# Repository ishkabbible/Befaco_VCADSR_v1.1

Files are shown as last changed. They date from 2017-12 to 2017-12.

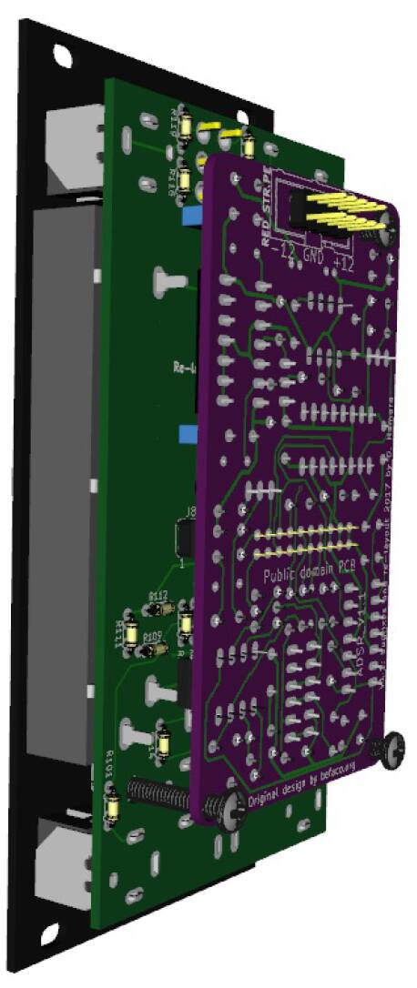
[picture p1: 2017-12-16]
full assembly 3D back final 2.jpg

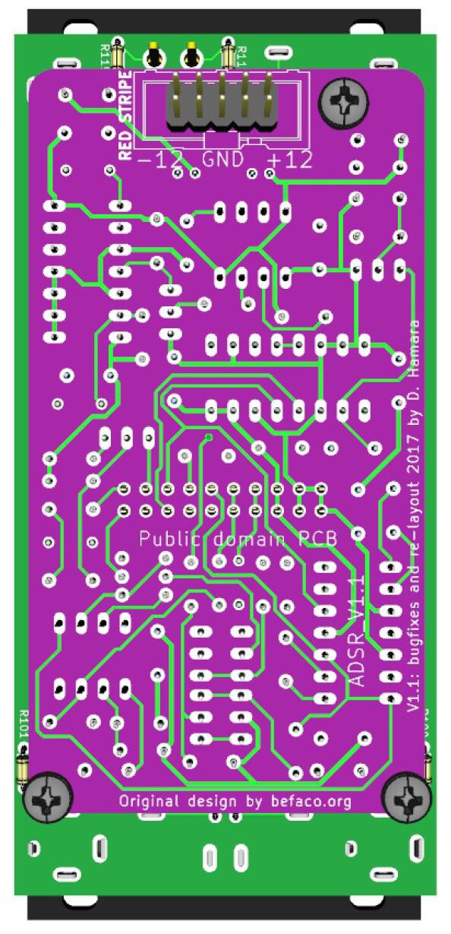
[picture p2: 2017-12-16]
full assembly 3D back final 1.jpg

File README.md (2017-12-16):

# Befaco_VCADSR_v1.1
Hamara Labs modified version of the Befaco version 1 VCADSR

The original files from Befaco are available here:
https://www.befaco.org/en/sinte-modular/en-produccion/vc-adsrv1/

Original design by Juergen Haible (http://www.jhaible.info/tonline_stuff/hj_vc_hadsr.html)

and Tom Gamble (http://synthdiy.fonitronik.de/files/4613/8287/9784/vcradsr.pdf)

I fixed a couple of bugs
  1) the inputs to the unused half of the 4013 were left floating - they are now properly grounded
  2) The trigger input to the used half of the 4013 was effectively floating whenever there was no gate input present, 
  due to the reverse biased D2. Added R26 to hold the trigger input at ground when D2 is reverse biased
  3) A retrigger bug was identified by someone somewhere, and photos of a haywire patch have been routinely distributed on line.
  That mod has been incorporated on the PCB as D6 and T8
  
I also updated the layout to use parts that are more readily available than the parts used in the original design. 
  
This repository contains 2 PCBs (FRONT and BACK) and one panel, all in KiCAD (http://kicad-pcb.org/)

The BOM is at https://docs.google.com/spreadsheets/d/1yNOWsHSHRAM60BiDUVynL0L72_J8PpAY8x3tWKFwJsM/edit?usp=sharing
This file takes precedence over the BOM in the assembly instructions document.

PCBs and panels *may* be available from Hamara Labs. Email HamaraLabs1 (at) gmail (dot) com to find out.

I believe all these files are correct, but I make no warranty whatsoever. Build at your own risk. If you find any problems with these files, please contact Hamara Labs at HamaraLabs1 (at) gmail (dot) com and I will update the files.

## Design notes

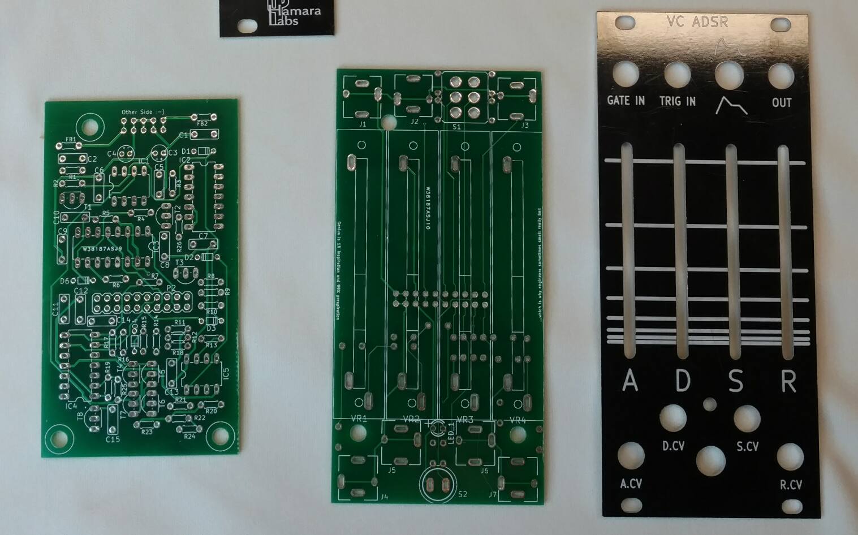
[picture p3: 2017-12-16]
VCADSR PCBs and panel.jpg

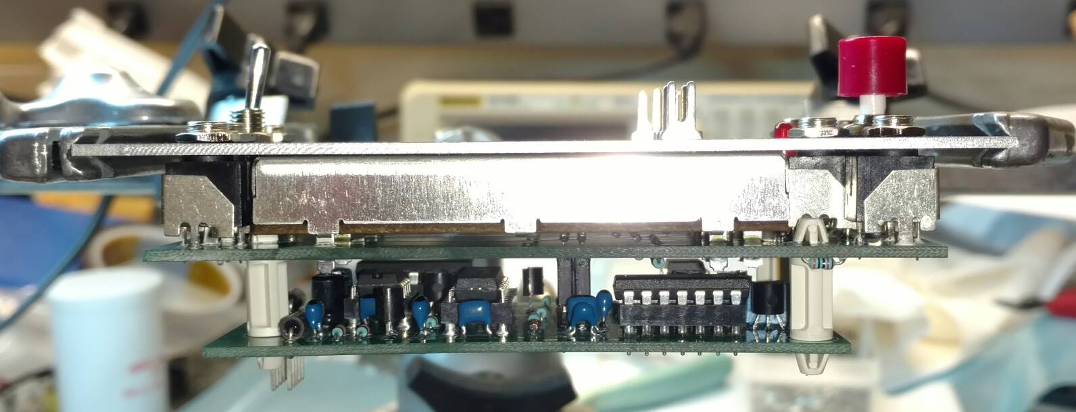
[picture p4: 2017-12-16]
VCADSR built 3 side view.jpg

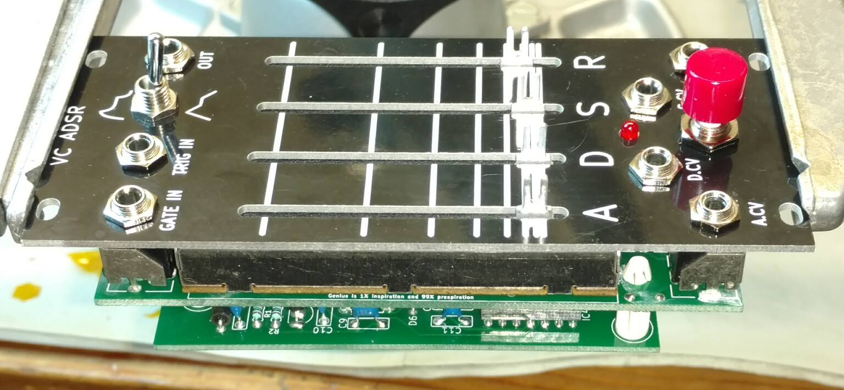
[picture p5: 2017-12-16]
VCADSR built 4 side perspective view.jpg

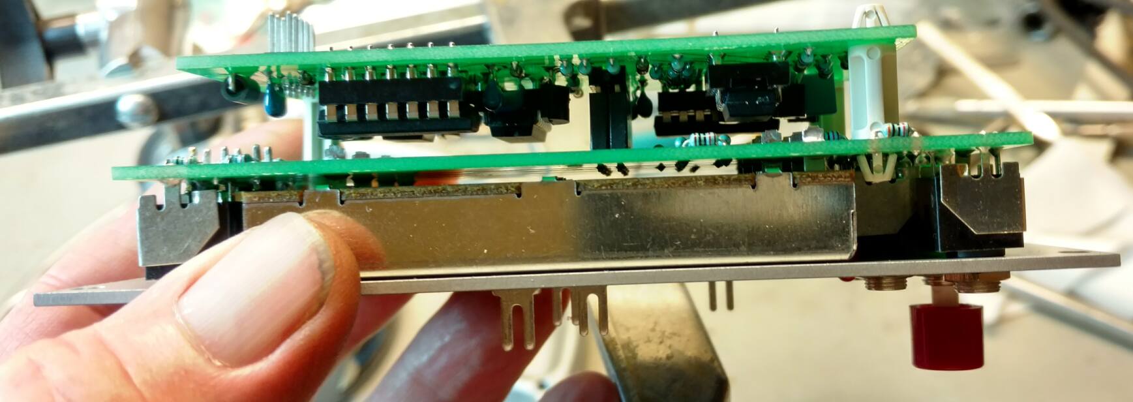
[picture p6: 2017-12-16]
VCADSR built 2 under sliders.jpg

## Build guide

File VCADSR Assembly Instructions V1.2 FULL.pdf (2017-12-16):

A

# Befa ssem

# co VC bly

2017

# CADS y Inst

# Dave Hamar

# SR V ructi

ra

1.1

# ons

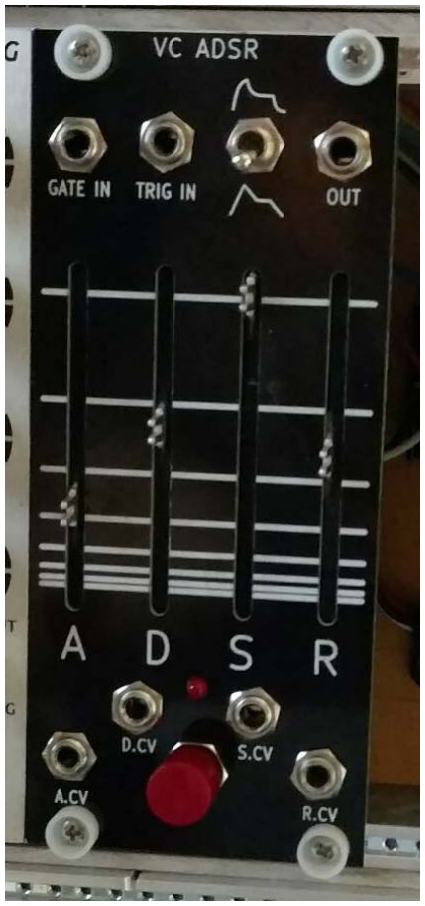
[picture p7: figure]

# Assembly Instructions

The back PCB assembly is very straightforward (Figure 1). Just remember that you only have 12mm of clearance between the 2 boards, so you don't want anything sticking up any farther than necessary. There IS room for low‐profile machined sockets (listed as OPTIONAL in the BOM) if you like socketing your chips.

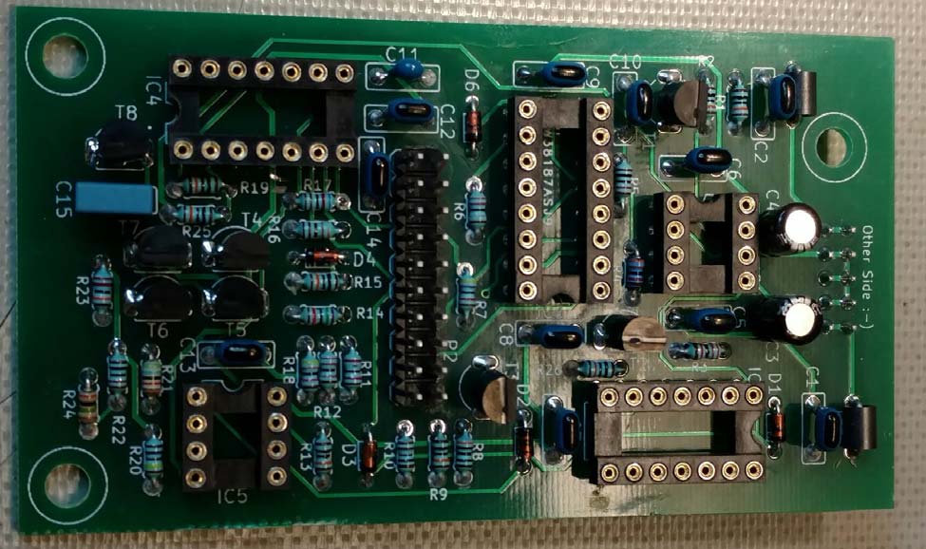
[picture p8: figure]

# Figure 1: Assembled BACK PCB. Mount T1 ‐ T8 close to the board

Assembly of the front PCB to the panel is a little tricky, because the pins for the inter‐board connector J8 and some of the resistors stick up underneath the sliders, so the sliders can not be mounted flush with the PCB (a holdover from the original Befaco design that I will rectify in a future version someday)

# The process is as follows:

1) Install all components (resistors and J8) on the bottom side of the front PCB (Figure 2)

# 2) Trim the leads on the top side as short as possible 3) Place all of the top side components except the LED on the board, but do not solder

4) If you use the pushbutton switch in the BOM, I found that putting the lock washer under the panel works best. Likewise, put the keying washer upside‐down on the toggle switch (see Figure 3)

# 5) Install the panel, and install and tighten the nuts on the jacks and switches

6) Gently separate the PCB from the panel by a couple mm, keeping the sliders flush with the panel, so you have good clearance between the bottom of the sliders and the resistor and J8

# leads. Keep the PCB and panel parallel to each other. (Figure 4)

7) Solder the jacks and switches. Note that the jack and pushbutton pins will probably not be sticking very far through the PCB ‐ this is OK, as the primary strength of the solder joints are inside the slots anyway.

# 8) Press the sliders flush against the front panel and solder their pins

9) Remove all the nuts, remove the panel, and place the LED in its proper location in the PCB

# (watch the polarity) 10) Reinstall the panel

11) Flip the assembly panel side down, and use the LED's leads to guide it into the hole in the panel. It will not fall through the panel due to the lip at the bottom of the LED. Press the LED as far into the hole as it will go, then solder and trim the leads.
12) Not strictly necessary, but I also trimmed the leads on the sliders, as some of them *can*

# interfere with parts on the back PCB, depending on how straight and low you installed

everything on the back PCB.

Since the PCB supports are a bit of a pain to unlock, this is a good time to just plug the back board and front board together for a test before installing the supports, just in case you need to fix anything. The power connector on the back PCB should be at the top.

Finally, install the PCB supports into the front PCB (Figure 5 ‐ note that the one at the top might need to be twisted back and forth a bit to get it to lock ‐ I didn't leave quite enough clearance for the little "wings" to flip out). Then snap the back PCB on, and you are done.

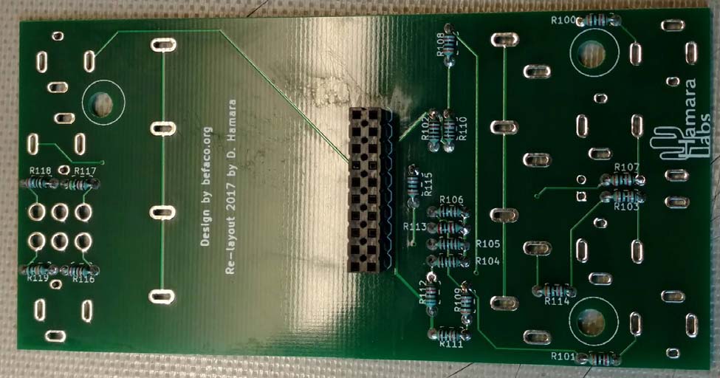
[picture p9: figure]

# Figure 2: Bottom side components on the FRONT PCB

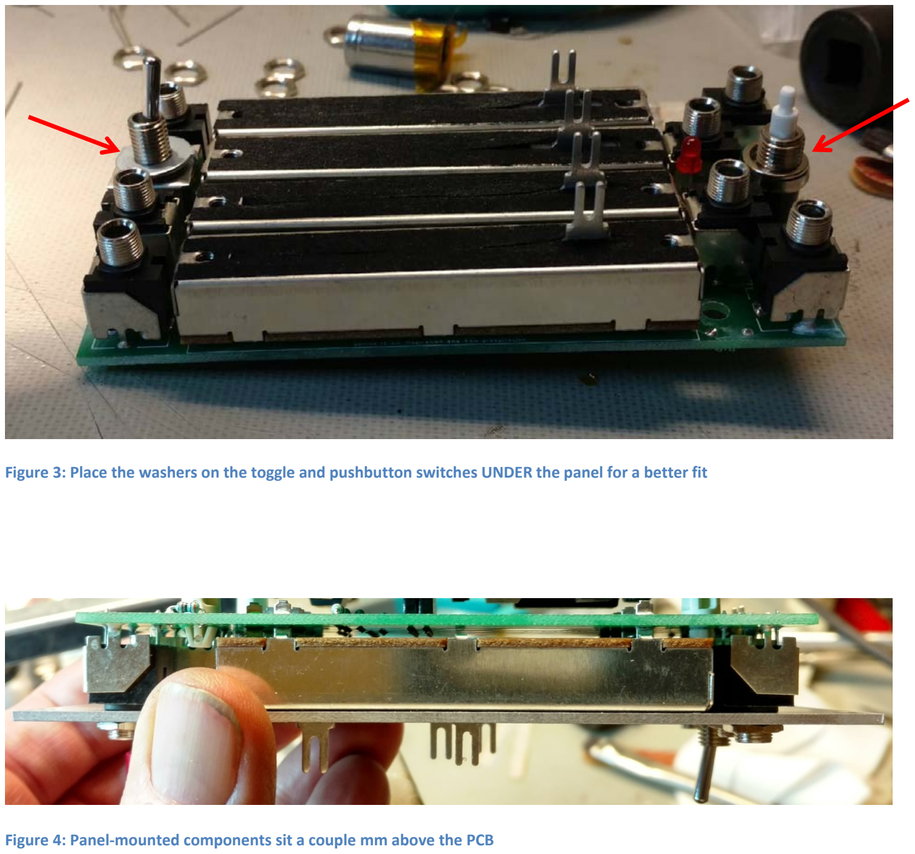
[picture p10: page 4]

Figure 3: Place the washers on the toggle and pushbutton switches UNDER the panel for a better fit

# Figure 4: Panel‐mounted components sit a couple mm above the PCB

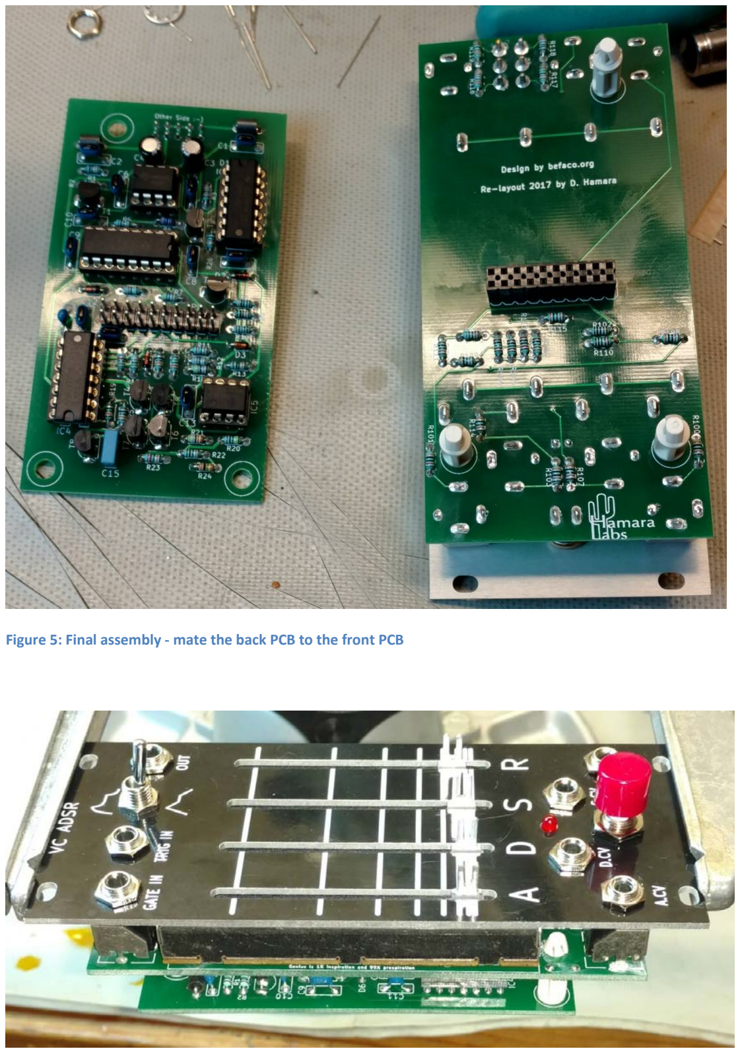
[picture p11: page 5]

# Figure 5: Final assembly ‐ mate the back PCB to the front PCB

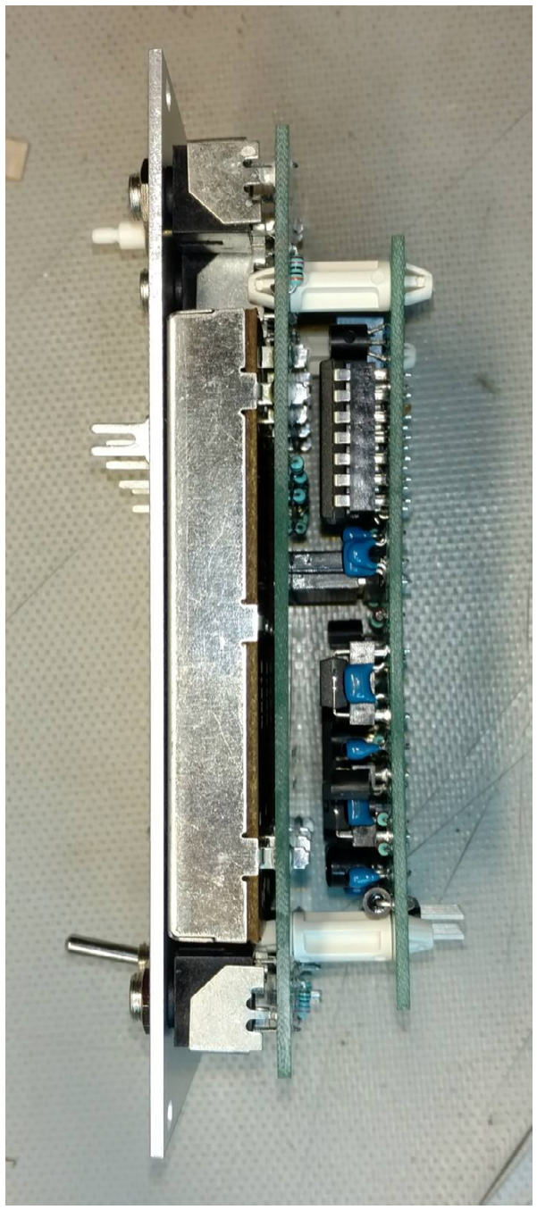
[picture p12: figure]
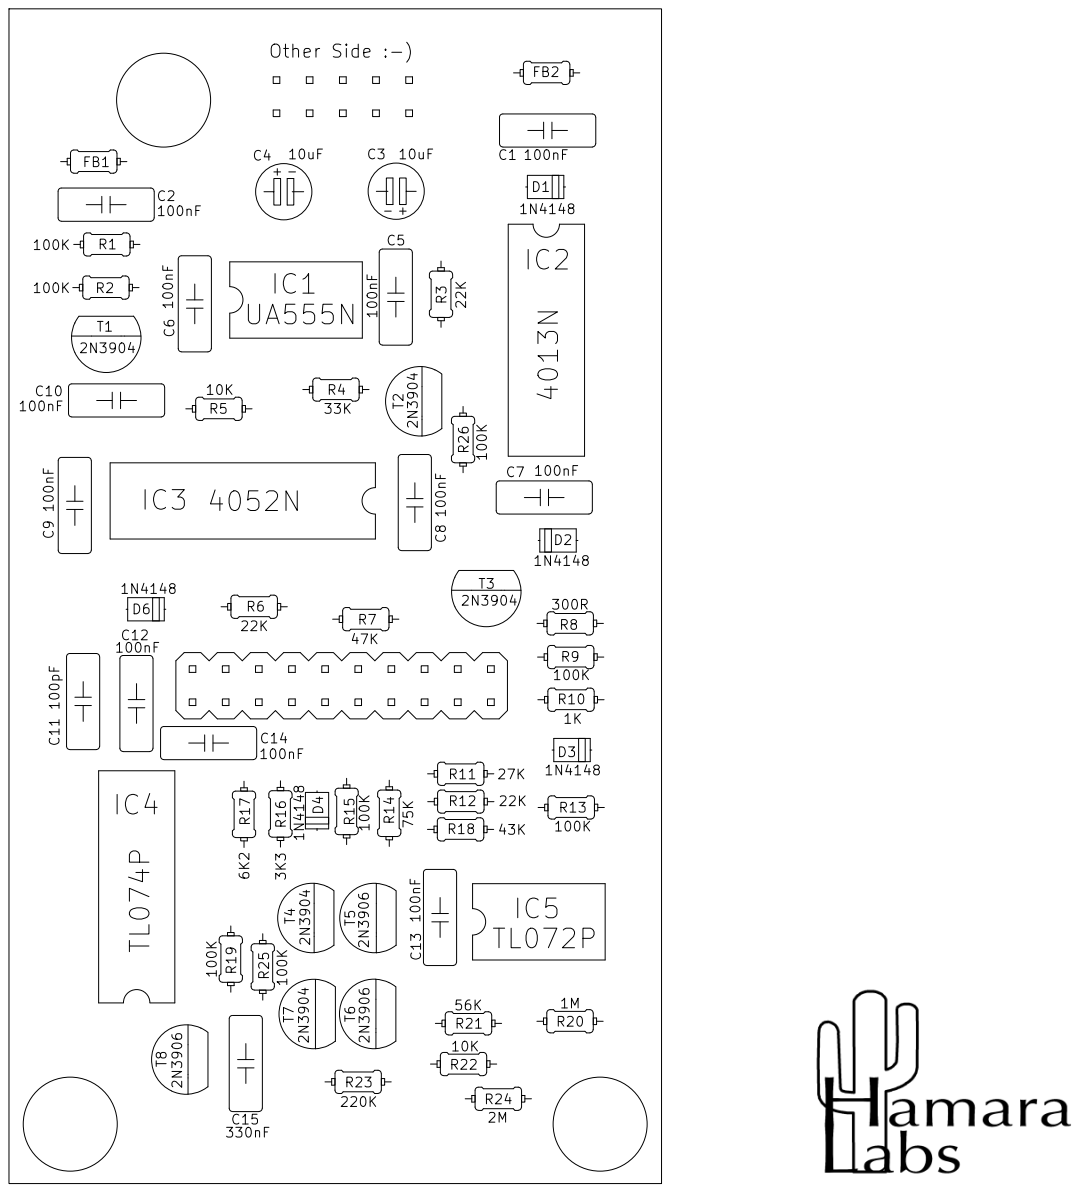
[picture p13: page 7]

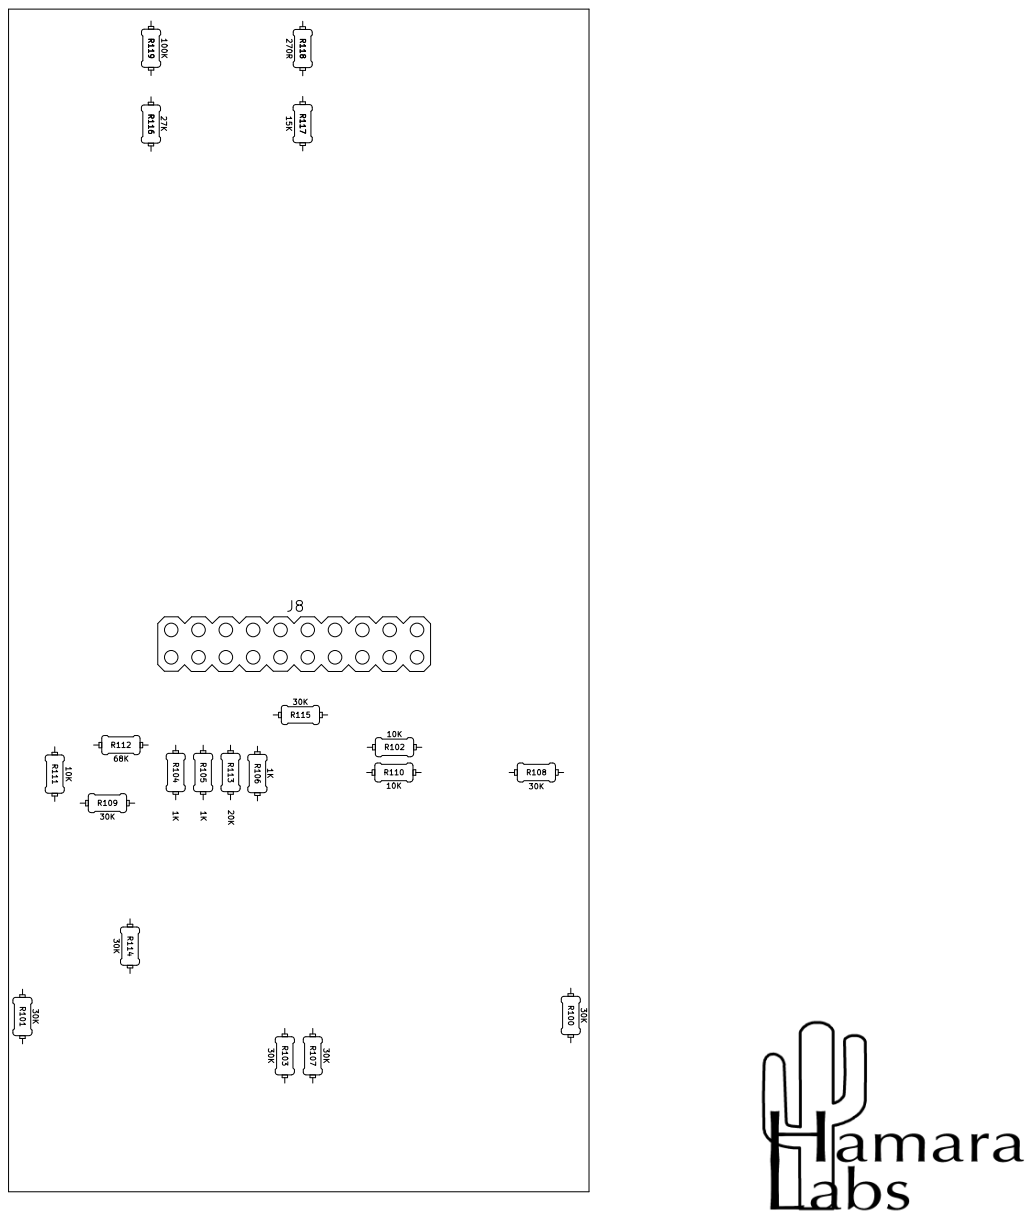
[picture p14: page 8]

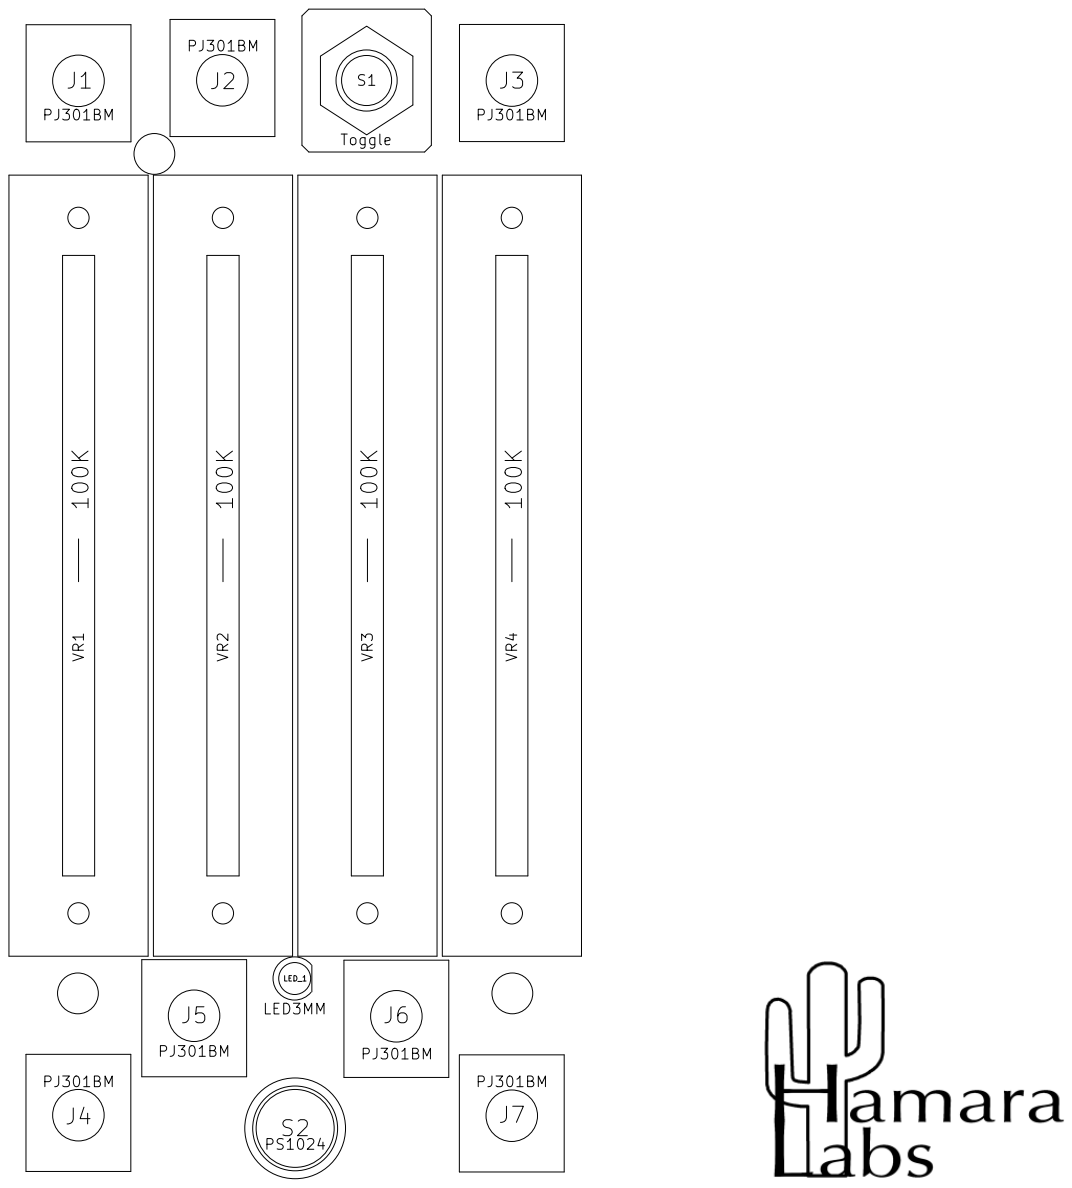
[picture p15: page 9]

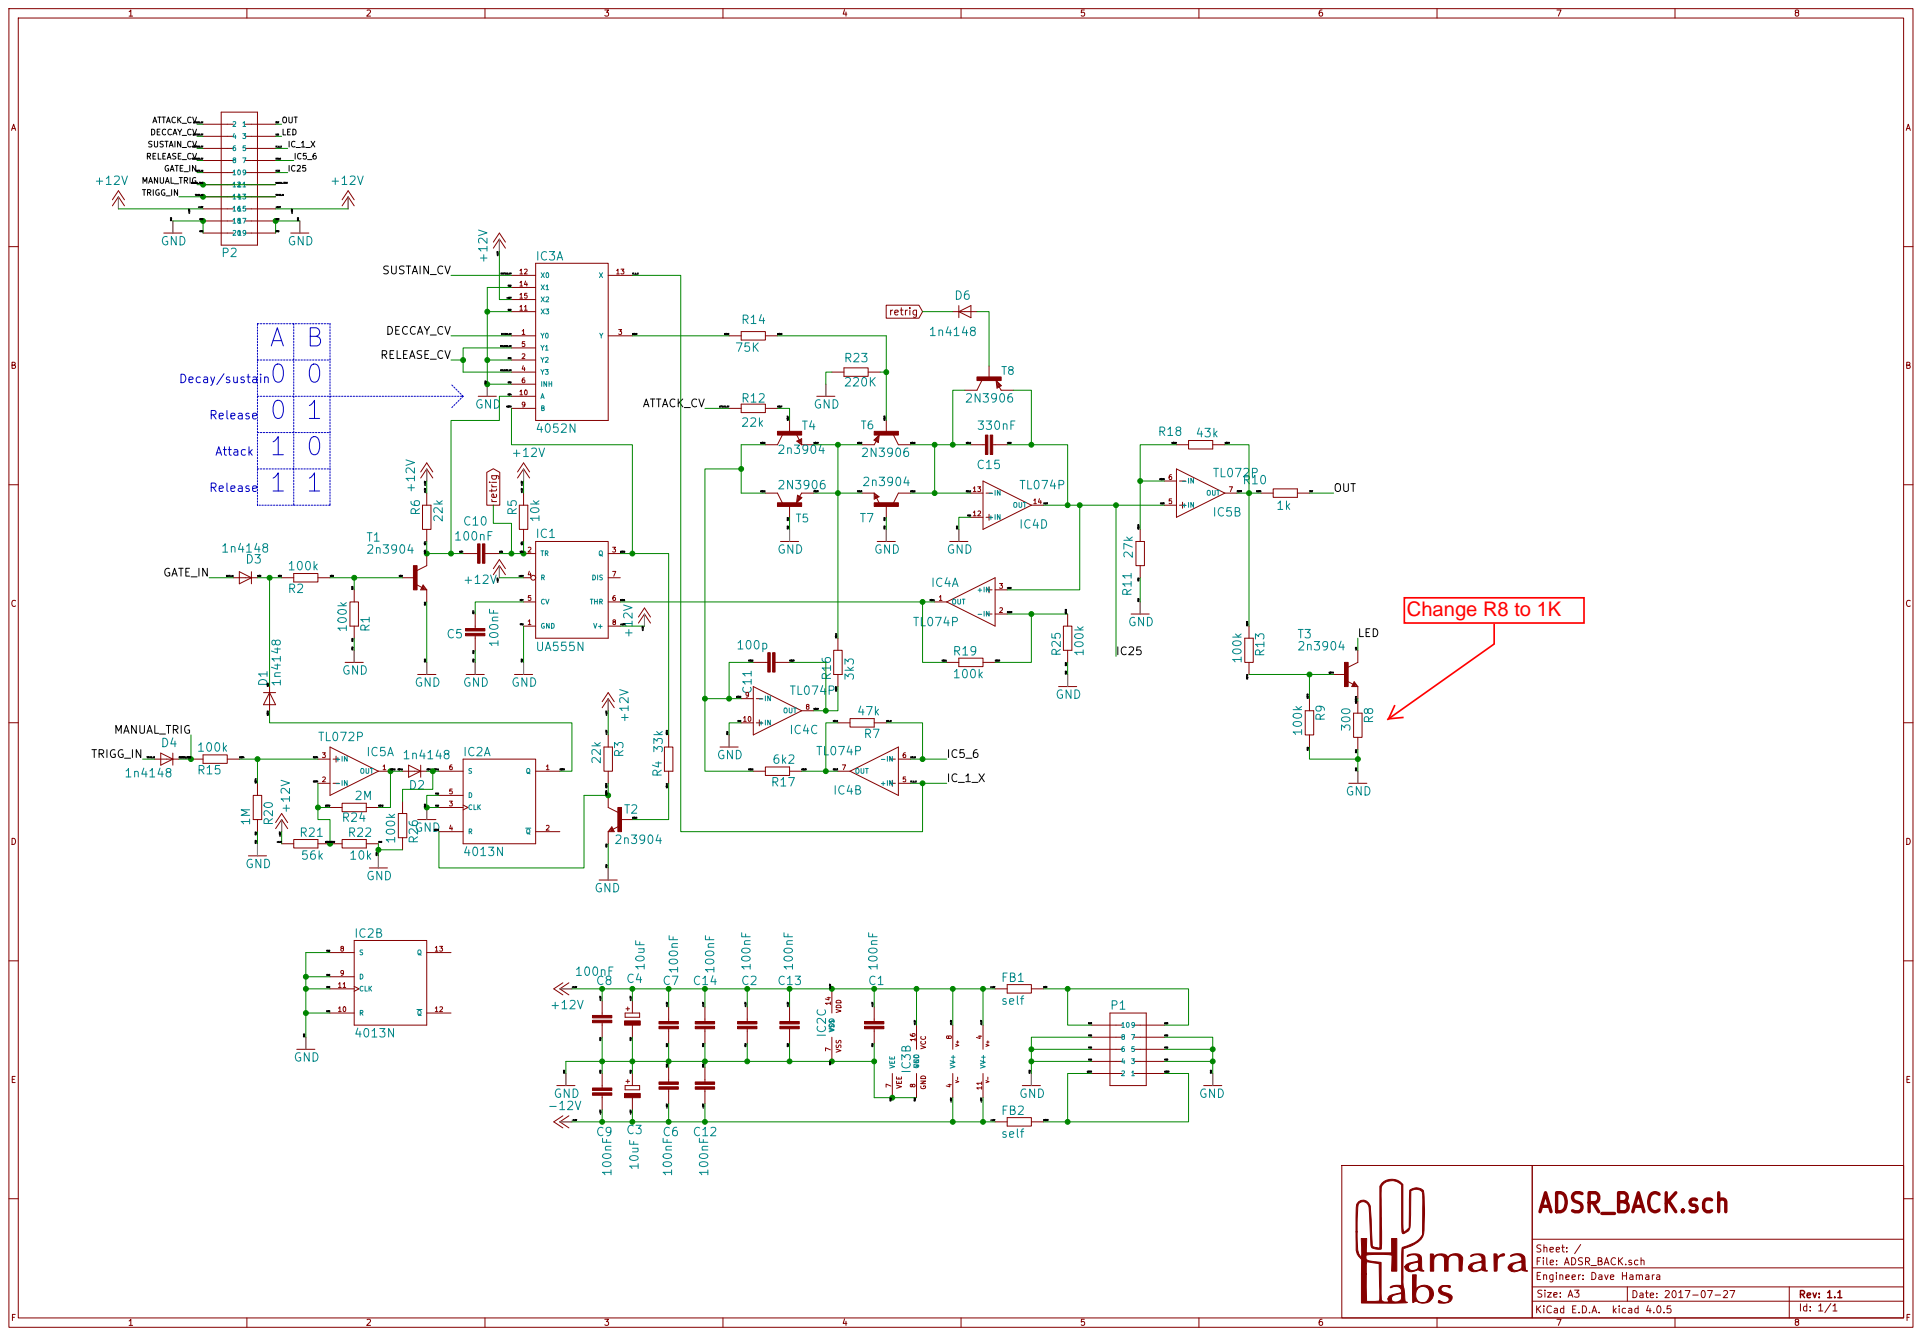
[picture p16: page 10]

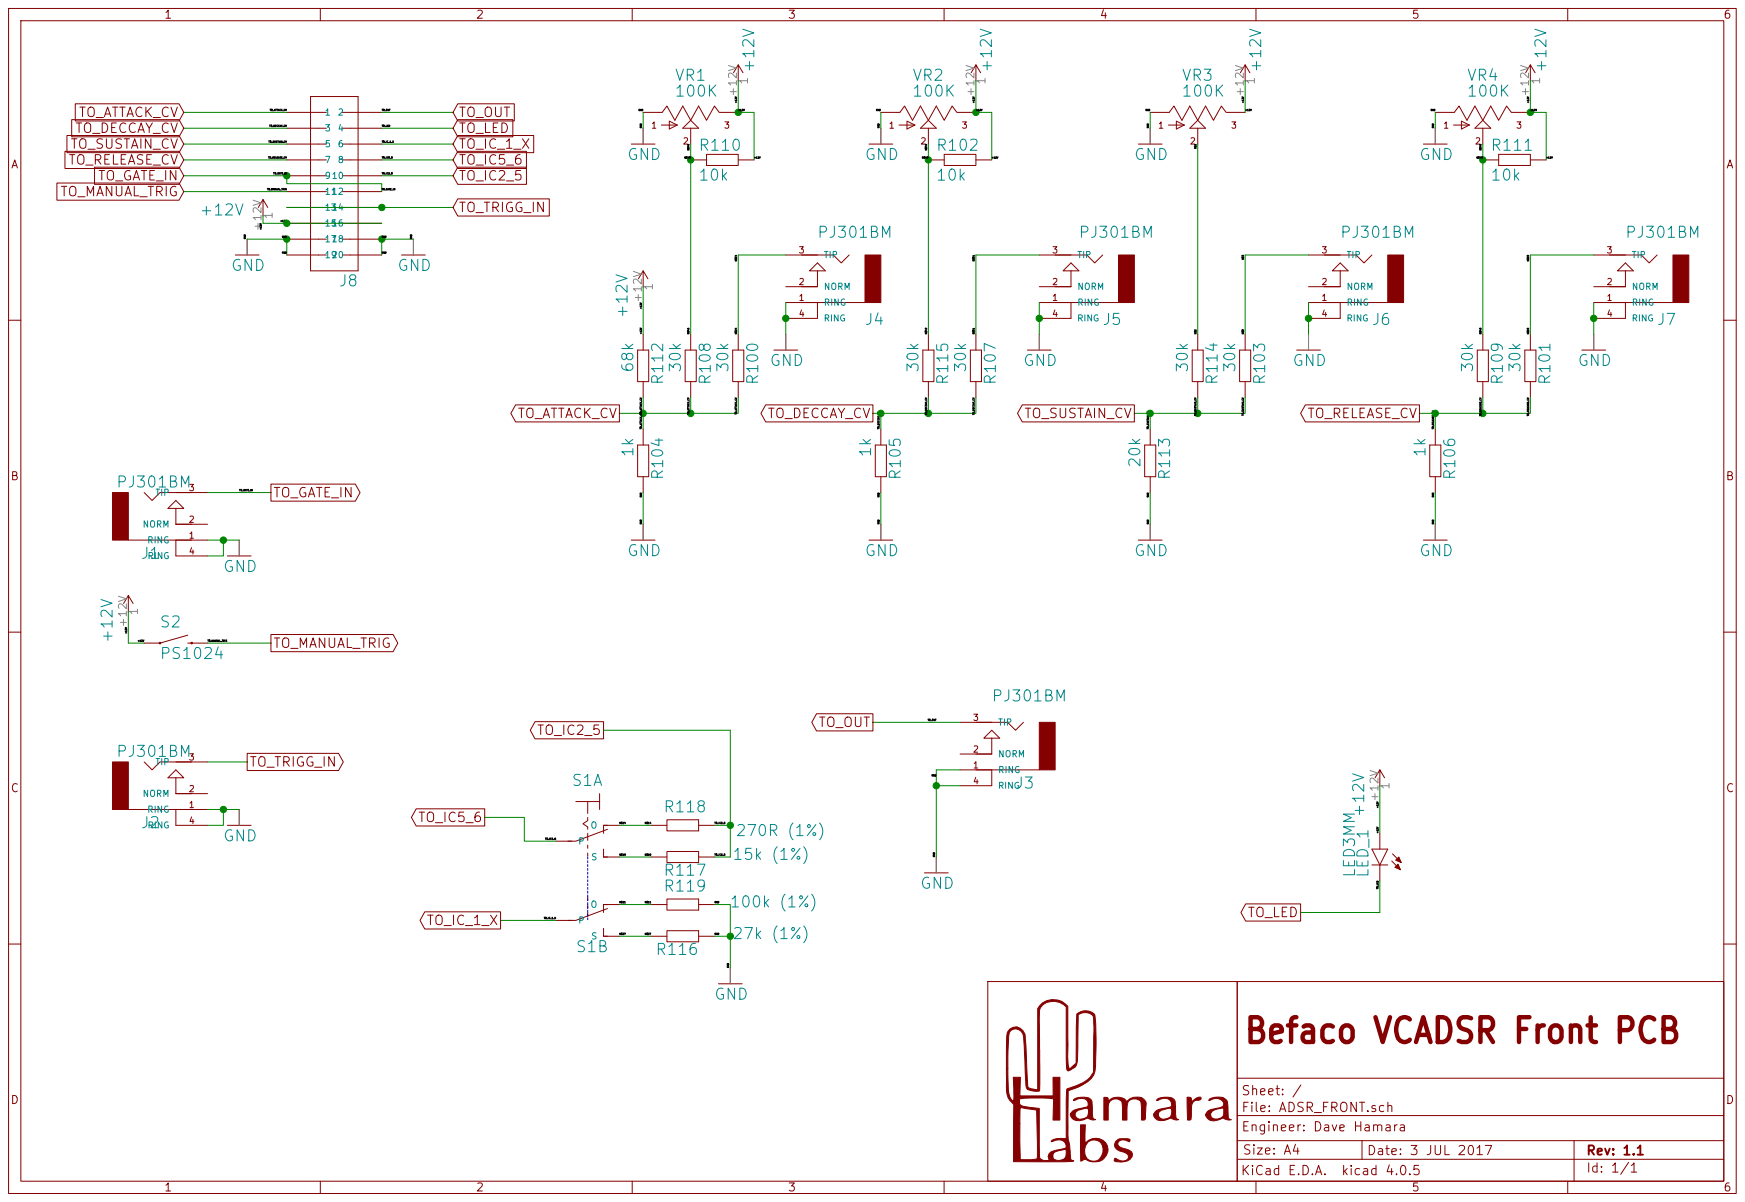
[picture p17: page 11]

Quantity Back | RefDes Back | Quantity Front | RefDes Front | Total Quantity | Value | Misc | Description | Vendor1 | Vendor part 1 | Vendor Link 1 | | Vendor 2 | Vendor part 2 | Vendor Link 2 | Vendor 3 | Vendor Part 3 | Vendor Link 3 | Vendor Link 3a
11 | C1,C2,C5,C6,C7,C8,C9,C10,C12,C13,C14 | | | 11 | 100nF | ≥50V | Radial ceramic cap, 5mm | Mouser | 594-K104K15X7RF53H5 | http://www.mouser.com/ProductDetail/Vishay-BC-Components/K104K15X7RF53H5/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 | | | | | Tayda | A-214 | http://www.taydaelectronics.com/0-1uf-50v-multilayer-ceramic-capacitor.html
1 | C11 | | | 1 | 100p | ≥50V | Radial ceramic cap, 5mm | Mouser | 75-1C20C0G101J050B | http://www.mouser.com/ProductDetail/Vishay-Sprague/1C20C0G101J050B/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 | | | | | Tayda | A-531 | http://www.taydaelectronics.com/10-x-100pf-50v-ceramic-disc-capacitor-pkg-of-10.html
1 | C15 | | | 1 | 330nF | ≥50V | Radial poly cap, 5mm (C0G ceramic will work) | Mouser | 871-B32529C334K189 | https://www.mouser.com/Search/ProductDetail.aspx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 | | | | | Tayda | A-566 | http://www.taydaelectronics.com/0-33uf-100v-5-polyester-film-box-type-capacitor.html
2 | C3,C4 | | | 2 | 10uF | ≥35V | Radial Aluminum, D=5mm, L=7mm, lead = 2mm | Mouser | 667-EEA-GA1V100H | http://www.mouser.com/ProductDetail/Panasonic/EEA-GA1V100H/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 | | | | | | This one is tough, they only have the taller version
| | | | | | | | | | | | | | | | | THP | 0805
8 | R1,R2,R9,R13,R15,R19,R25,R26 | 1 | R119 | 9 | 100K | | 1/8W, 3.3mm length, or SMT 0805 (Front only) | Mouser | 270-100K-RC | http://www.mouser.com/ProductDetail/Xicon/270-100K-RC/?qs=sGAEpiMZZMu61qfTUdNhG0T8NRN%2fRayjYP90eo1gO0Q%3d | | Digikey | RNF18FTD100KCT-ND | https://www.digikey.com/products/en?keywords=RNF18FTD100KCT-ND | Tayda | A-3825 | http://www.taydaelectronics.com/r-100k-ohm-1-8w-1-metal-film-resistor.html
2 | R5,R22 | 3 | R102,R110,R111 | 5 | 10K | | 1/8W, 3.3mm length, or SMT 0805 (Front only) | Mouser | 270-10K-RC | http://www.mouser.com/ProductDetail/Xicon/270-10K-RC/?qs=sGAEpiMZZMu61qfTUdNhG%2fNICg4NOtz5D3ChGIwXeqI%3d | | Digikey | S10KCACT-ND | https://www.digikey.com/products/en?keywords=S10KCACT-ND | Tayda | A-3795 | http://www.taydaelectronics.com/r-10k-ohm-1-8w-1-metal-film-resistor.html
| | 1 | R117 | 1 | 15K | | 1/8W, 3.3mm length, or SMT 0805 (Front only) | Mouser | 270-15K-RC | http://www.mouser.com/ProductDetail/Xicon/270-15K-RC/?qs=sGAEpiMZZMu61qfTUdNhG0T8NRN%2fRayjnXHG3sBXkqE%3d | | Digikey | RNF18FTD15K0CT-ND | https://www.digikey.com/products/en?keywords=RNF18FTD15K0CT-ND | Tayda | A-3803 (A-3093) | http://www.taydaelectronics.com/r-15k-ohm-1-8w-1-metal-film-resistor.html | http://www.taydaelectronics.com/50-x-smd-chip-resistors-15k-ohm-1-8w-1-0805.html
1 | R8, R10 | 3 | R104,R105,R106 | 4 | 1K | | 1/8W, 3.3mm length, or SMT 0805 (Front only) | Mouser | 270-1K-RC | http://www.mouser.com/ProductDetail/Xicon/270-1K-RC/?qs=sGAEpiMZZMu61qfTUdNhGycWKXxEhBp7sB6G%2fdTuvOM%3d | | Digikey | RNF18FTD1K00CT-ND | https://www.digikey.com/products/en?keywords=RNF18FTD1K00CT-ND | Tayda | A-3772 (A-3065) | http://www.taydaelectronics.com/r-1k-ohm-1-8w-1-metal-film-resistor.html | http://www.taydaelectronics.com/50-x-smd-chip-resistors-1-0k-ohm-1-8w-1-0805.html
1 | R20 | | | 1 | 1M | | 1/8W, 3.3mm length | Mouser | 270-1.0M-RC | http://www.mouser.com/ProductDetail/Xicon/270-10M-RC/?qs=sGAEpiMZZMu61qfTUdNhG1VZapgQ2mzw5GSB6LCokiA%3d | | Digikey | RNF18FTD1M00CT-ND | https://www.digikey.com/products/en?keywords=RNF18FTD1M00CT-ND | Tayda | A-3852 | http://www.taydaelectronics.com/r-1m-ohm-1-8w-1-metal-film-resistor.html
| | 1 | R113 | 1 | 20K | | 1/8W, 3.3mm length, or SMT 0805 (Front only) | Mouser | 270-20K-RC | http://www.mouser.com/ProductDetail/Xicon/270-20K-RC/?qs=sGAEpiMZZMu61qfTUdNhG01iKAfFMHZrJE%2fwU1671ts%3d | | Digikey | RNF18FTD20K0CT-ND | https://www.digikey.com/products/en?keywords=RNF18FTD20K0CT-ND | Tayda | A-3807 (A-3096) | http://www.taydaelectronics.com/r-20k-ohm-1-8w-1-metal-film-resistor.html | http://www.taydaelectronics.com/50-x-smd-chip-resistors-20k-ohm-1-8w-1-0805.html
1 | R23 | | | 1 | 220K | | 1/8W, 3.3mm length | Mouser | 270-220K-RC | http://www.mouser.com/ProductDetail/Xicon/270-220K-RC/?qs=sGAEpiMZZMu61qfTUdNhG15Sz3PBOPbZ%252bXemycOErKw%3d | | Digikey | S220KCACT-ND | https://www.digikey.com/products/en?keywords=S220KCACT-ND | Tayda | A-3836 | http://www.taydaelectronics.com/r-220k-ohm-1-8w-1-metal-film-resistor.html
3 | R3,R6,R12 | | | 3 | 22K | | 1/8W, 3.3mm length | Mouser | 270-22K-RC | http://www.mouser.com/ProductDetail/Xicon/270-22K-RC/?qs=sGAEpiMZZMu61qfTUdNhG%252bYGOpalelFJxxOz8xQD5cg%3d | | Digikey | S22KCACT-ND | https://www.digikey.com/products/en?keywords=S22KCACT-ND | Tayda | A-3808 | http://www.taydaelectronics.com/r-22k-ohm-1-8w-1-metal-film-resistor.html
| | 1 | R118 | 1 | 270R | | 1/8W, 3.3mm length, or SMT 0805 (Front only) | Mouser | 270-270-RC | http://www.mouser.com/ProductDetail/Xicon/270-270-RC/?qs=sGAEpiMZZMu61qfTUdNhGx2g6h6o0XudDLlTq%2fy7K8o%3d | | Digikey | S270CACT-ND | https://www.digikey.com/products/en?keywords=S270CACT-ND | Tayda | A-3758 (A-3051) | http://www.taydaelectronics.com/59709-dup-r-5-1-ohm-1-8w-1-metal-film-resistor.html | http://www.taydaelectronics.com/50-x-smd-chip-resistors-270-ohm-1-8w-1-0805.html
1 | R11 | 1 | R116 | 2 | 27K | | 1/8W, 3.3mm length, or SMT 0805 (Front only) | Mouser | 270-27K-RC | http://www.mouser.com/ProductDetail/Xicon/270-27K-RC/?qs=sGAEpiMZZMu61qfTUdNhG8DCUhfQWu4hLI18cywVbvQ%3d | | Digikey | S27KCACT-ND | https://www.digikey.com/products/en?keywords=S27KCACT-ND | Tayda | A-3810 (A-3099) | http://www.taydaelectronics.com/95833-dup-r-12-4-ohm-1-8w-1-metal-film-resistor.html | http://www.taydaelectronics.com/50-x-smd-chip-resistors-27k-ohm-1-8w-1-0805.html
1 | R24 | | | 1 | 2M | | 1/8W, 3.3mm length | Mouser | 299-2M-RC | http://www.mouser.com/ProductDetail/Xicon/299-2M-RC/?qs=sGAEpiMZZMu61qfTUdNhG%252b0AOBcthSuGf%2fgnVpsVzY8%3d | | | | | Tayda | A-3858 | http://www.taydaelectronics.com/90282-dup-r-12-4-ohm-1-8w-1-metal-film-resistor.html
| | 8 | R100,R101,R103,R107,R108,R109,R114,R115 | 8 | 30K | | 1/8W, 3.3mm length, or SMT 0805 (Front only) | Mouser | 270-30K-RC | http://www.mouser.com/ProductDetail/Xicon/270-30K-RC/?qs=sGAEpiMZZMu61qfTUdNhG3rFkoq2Hf1ayuDgvp4lvkI%3d | | Digikey | S30KCACT-ND | https://www.digikey.com/products/en?keywords=S30KCACT-ND
1 | R4 | | | 1 | 33K | | 1/8W, 3.3mm length | Mouser | 270-33K-RC | http://www.mouser.com/ProductDetail/Xicon/270-33K-RC/?qs=sGAEpiMZZMu61qfTUdNhG3Nx2NnrbLsFD96SSQZAP%252bI%3d | | Digikey | RNMF14FTC33K0CT-ND | https://www.digikey.com/product-detail/en/stackpole-electronics-inc/RNMF14FTC33K0/RNMF14FTC33K0CT-ND/4770675 | Tayda | A-3812 (A-3100) | http://www.taydaelectronics.com/83014-dup-r-12-4-ohm-1-8w-1-metal-film-resistor.html | http://www.taydaelectronics.com/50-x-smd-chip-resistors-30k-ohm-1-8w-1-0805.html
1 | R16 | | | 1 | 3k3 | | 1/8W, 3.3mm length | Mouser | 270-3.3K-RC | http://www.mouser.com/ProductDetail/Xicon/270-33K-RC/?qs=0x0kLJ2FD7%2fl6dcuCCT4Dg%3d%3d | | Digikey | S3.3KCACT-ND | https://www.digikey.com/products/en?keywords=S3.3KCACT-ND | Tayda | A-3813 | http://www.taydaelectronics.com/r-33k-ohm-1-8w-1-metal-film-resistor.html
1 | R18 | | | 1 | 43K | | 1/8W, 3.3mm length | Mouser | 270-43K-RC | http://www.mouser.com/ProductDetail/Xicon/270-43K-RC/?qs=sGAEpiMZZMu61qfTUdNhG8DCUhfQWu4h1oiyr0K0jvM%3d | | Digikey | S43KCACT-ND | https://www.digikey.com/products/en?keywords=S43KCACT-ND | Tayda | A-3783 | http://www.taydaelectronics.com/5342-dup-r-5-1-ohm-1-8w-1-metal-film-resistor.html
1 | R7 | | | 1 | 47K | | 1/8W, 3.3mm length | Mouser | 270-47K-RC | http://www.mouser.com/ProductDetail/Xicon/270-47K-RC/?qs=sGAEpiMZZMu61qfTUdNhG3eQrhCSzV9q5hbd2ss8Kkg%3d | | Digikey | S47KCACT-ND | https://www.digikey.com/products/en?keywords=S47KCACT-ND | Tayda | A-3816 | http://www.taydaelectronics.com/93428-dup-r-12-4-ohm-1-8w-1-metal-film-resistor.html
1 | R21 | | | 1 | 56K | | 1/8W, 3.3mm length | Mouser | 270-56K-RC | http://www.mouser.com/ProductDetail/Xicon/270-56K-RC/?qs=sGAEpiMZZMu61qfTUdNhG2ZzrN2CiS9n20OyeRmC%2fHk%3d | | Digikey | P56.0KCACT-ND | https://www.digikey.com/products/en?keywords=P56.0KCACT-ND | Tayda | A-3817 | http://www.taydaelectronics.com/29252-dup-r-12-4-ohm-1-8w-1-metal-film-resistor.html
| | 1 | R112 | 1 | 68K | | 1/8W, 3.3mm length, or SMT 0805 (Front only) | Mouser | 270-68K-RC | http://www.mouser.com/ProductDetail/Xicon/270-68K-RC/?qs=sGAEpiMZZMu61qfTUdNhGx2g6h6o0XudkZS%2f7qbPiAE%3d | | Digikey | S68KCACT-ND | https://www.digikey.com/products/en?keywords=S68KCACT-ND | Tayda | A-3819 | http://www.taydaelectronics.com/38013-dup-r-12-4-ohm-1-8w-1-metal-film-resistor.html
1 | R17 | | | 1 | 6k2 | | 1/8W, 3.3mm length | Mouser | 270-6.2K-RC | http://www.mouser.com/ProductDetail/Xicon/270-62K-RC/?qs=sGAEpiMZZMu61qfTUdNhGzu9JZ8bMiQTQhv569DgB%2fM%3d | | Digikey | S6.2KCACT-ND | https://www.digikey.com/products/en?keywords=S6.2KCACT-ND | Tayda | A-3821 (A-3109) | http://www.taydaelectronics.com/79833-dup-r-12-4-ohm-1-8w-1-metal-film-resistor.html | http://www.taydaelectronics.com/50-x-smd-chip-resistors-68k-ohm-1-8w-1-0805.html
1 | R14 | | | 1 | 75K | | 1/8W, 3.3mm length | Mouser | 270-75K-RC | http://www.mouser.com/ProductDetail/Xicon/270-75K-RC/?qs=sGAEpiMZZMu61qfTUdNhG9rLbwLhtOUuTqe0iz%252bo%2frs%3d | | Digikey | S75KCACT-ND | https://www.digikey.com/products/en?keywords=S75KCACT-ND | Tayda | A-3790 | http://www.taydaelectronics.com/27101-dup-r-5-1-ohm-1-8w-1-metal-film-resistor.html
| | | | | | | | | | | | | | | Tayda | A-3822 | http://www.taydaelectronics.com/r-75k-ohm-1-8w-1-metal-film-resistor.html
5 | D1,D2,D3,D4,D6 | | | 5 | 1n4148 | | Small Signal Diode, DO-35 | Mouser | 512-1N4148 | http://www.mouser.com/ProductDetail/ON-Semiconductor-Fairchild/1N4148/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 | |
5 | T1,T2,T3,T4,T7 | | | 5 | 2N3904 | | TRANSISTOR, NPN, TO92 | Mouser | 512-2N3904TA | http://www.mouser.com/ProductDetail/ON-Semiconductor-Fairchild/2N3904TA/?qs=sGAEpiMZZMvAvBNgSS9Lqp8aB%2fMLlILd | | | | | Tayda | A-157 | http://www.taydaelectronics.com/1n4148-switching-signal-diode.html
3 | T5,T6,T8 | | | 3 | 2N3906 | | TRANSISTOR, PNP, TO92 | Mouser | 512-2N3906TA | http://www.mouser.com/ProductDetail/ON-Semiconductor-Fairchild/2N3906TA/?qs=sGAEpiMZZMtdAabcSkQOl1OzvBxEIajd | | | | | Tayda | A-111 | http://www.taydaelectronics.com/2n3904-npn-general-propose-transistor.html
1 | IC1 | | | 1 | UA555N | | Timer | Mouser | 595-NE555P | https://www.mouser.com/Search/ProductDetail.aspx?R=NE555Pvirtualkey59500000virtualkey595-NE555P | | | | | Tayda | A-117 | http://www.taydaelectronics.com/2n3906-general-propose-pnp-transistor.html
1 | IC2 | | | 1 | 4013N | | Dual Flip Flop | Mouser | 595-CD4013BE | https://www.mouser.com/Search/ProductDetail.aspx?R=CD4013BEvirtualkey59500000virtualkey595-CD4013BE | | | | | Tayda | A-249 | http://www.taydaelectronics.com/ne555-ic-555-timer-dip-8.html
1 | IC3 | | | 1 | 4052N | | Dual 4-1 analog mux | Mouser | 595-CD4052BE | https://www.mouser.com/Search/ProductDetail.aspx?R=CD4052BEvirtualkey59500000virtualkey595-CD4052BE | | | | | Tayda | A-556 | http://www.taydaelectronics.com/cd4013-4013-ic-cmos-dual-d-flip-flop.html
1 | IC4 | | | 1 | TL074P | | Quad op-amp | Mouser | 595-TL074CN | http://www.mouser.com/ProductDetail/Texas-Instruments/TL074CN/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 | | | | | Tayda | A-1150 | http://www.taydaelectronics.com/cd4052-4052-cmos-multiplex-demultiplexer-ic.html
1 | IC5 | | | 1 | TL072P | | Dial op-amp | Mouser | 595-TL072IP | https://www.mouser.com/Search/ProductDetail.aspx?R=TL072IPvirtualkey59500000virtualkey595-TL072IP | | | | | Tayda | A-1138 | http://www.taydaelectronics.com/tl074-quad-operational-amplifier-j-fet-pdip-14-tl074cn.html
| | 1 | LED_1 | 1 | LED3MM | | 3mm (T1) LED (any one will do) | Mouser | 859-LTL-4221 | http://www.mouser.com/ProductDetail/Lite-On/LTL-4221/?qs=sGAEpiMZZMvHYEB9WUp7Ej7BQBhOZen2zKojyGe3kJs%3d | | | | | Tayda | A-037 | http://www.taydaelectronics.com/tl072-low-noise-j-fet-dual-op-amp-ic.html
| | | | | | | | | | | | | | | Tayda | A-261 | http://www.taydaelectronics.com/led-3mm-red.html
2 | FB1,FB2 | | | 2 | Ferrite Beads | | BEAD ON LEAD Z=68 OHM @ 100MHz | Mouser | 623-2743001112LF | http://www.mouser.com/Search/ProductDetail.aspx?R=2743001112virtualkey62300000virtualkey623-2743001112LF | |
| | | | | | | | | | | | | | | | They dont sell ferrite beads apparently.
| | 4 | VR1,VR2,VR3,VR4 | 4 | 100K | | Befaco_VCADSR_SLIDER | Ali Express | | https://www.aliexpress.com/item/Free-Shipping-10pcs-B50K-B100K-Potentiometer-Audio-Slide-Pot-Resistor/1670003362.html | |
| | 1 | S2 | 1 | PS1024 | | SPST Pushbutton Switch | Mouser | 612-PS1024AL-RED | http://www.mouser.com/Search/ProductDetail.aspx?R=PS1024AL-REDvirtualkey61200000virtualkey612-PS1024AL-RED | |
| | 1 | S1 | 1 | Toggle | | DPDT miniature toggle switch | Mouser | 108-1MD1T2B3M2QE-EVX | http://www.mouser.com/Search/ProductDetail.aspx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 | | Digikey | EG2400-ND | https://www.digikey.com/product-detail/en/e-switch/100DP1T1B1M2QEH/EG2400-ND/378869 | Tayda | A-5051 | http://www.taydaelectronics.com/pb-11d02-push-button-panel-mount-spst-no-pb-11d02-th1r00.html | <-- might work depends on size.
| | 1 | J8 | 1 | Header | | 10x2 female 0.1" pitch header, 8.26mm high | Mouser | 517-929852-01-10-RB | http://www.mouser.com/Search/ProductDetail.aspx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 | | | | | Tayda | A-4568 | http://www.taydaelectronics.com/mini-toggle-switch-dpdt-on-on.html
| | 7 | J7,J1,J2,J3,J4,J5,J6 | 7 | PJ301BM | | PJ301BM-JACK-slots | Thonk | PJ301BM | https://www.thonk.co.uk/shop/3-5mm-jacks/ | | | | | Tayda | A-1690 | http://www.taydaelectronics.com/2x10-pin-2-54mm-double-row-female-pin-header.html | <-- the mouser part is nicer because it looks like they break cleaner, but these are similar
1 | P2 | | | 1 | Header | | 10x2 male 0.1" pitch header | | | | | Digikey | S2011EC-10-ND | https://www.digikey.com/product-detail/en/sullins-connector-solutions/PRPC010DAAN-RC/S2011EC-10-ND/2775284
1 | P1 | | | 1 | power | | 5x2 male 0.1" pitch header | | | | | Digikey | S2012EC-05-ND | https://www.digikey.com/product-detail/en/sullins-connector-solutions/PREC005DAAN-RC/S2012EC-05-ND/2774889 | Tayda | A-198 | http://www.taydaelectronics.com/2x40-pin-2-54-mm-double-row-pin-header-strip.html
| | | | | | | | | | | | | | | Tayda | A-198 | http://www.taydaelectronics.com/2x40-pin-2-54-mm-double-row-pin-header-strip.html
3 | H1, H2, H3 | | | 3 | | | PCB support, 12mm | Mouser | 534-8848 | http://www.mouser.com/Search/ProductDetail.aspx?R=8848virtualkey53400000virtualkey534-8848 | |
1 | | | | 1 | | | Front PCB | HamaraLabs | | | |
1 | | | | 1 | | | Back PCB | HamaraLabs | | | |
1 | | | | 1 | | | panel | HamaraLabs
| OPTIONAL | | | | | |
2 | IC1, IC5 | 2 | Low profile 8-pin DIP socket | 575-343308 | http://www.mouser.com/ProductDetail/Mill-Max/115-43-308-41-003000/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 | |
2 | IC2, IC4 | 2 | Low profile 14-pin DIP socket | 575-893314 | http://www.mouser.com/ProductDetail/Mill-Max/115-93-314-41-001000/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 | |
1 | IC3 | 1 | Low profile 16-pin DIP socket | 575-393316 | http://www.mouser.com/ProductDetail/Mill-Max/115-93-316-41-003000/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 | |

total parts

kit cost

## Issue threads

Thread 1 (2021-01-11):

Gerber files

strpstv, 2021-01-11:
Hi there! thanks a lot for your design and sharing it with us :) I don't know much about gerber files and can't seem to upload the gerber folder on pcb manufacturer's site. Would you mind pointing me towards what i'm failing to see here? thanks a lot!

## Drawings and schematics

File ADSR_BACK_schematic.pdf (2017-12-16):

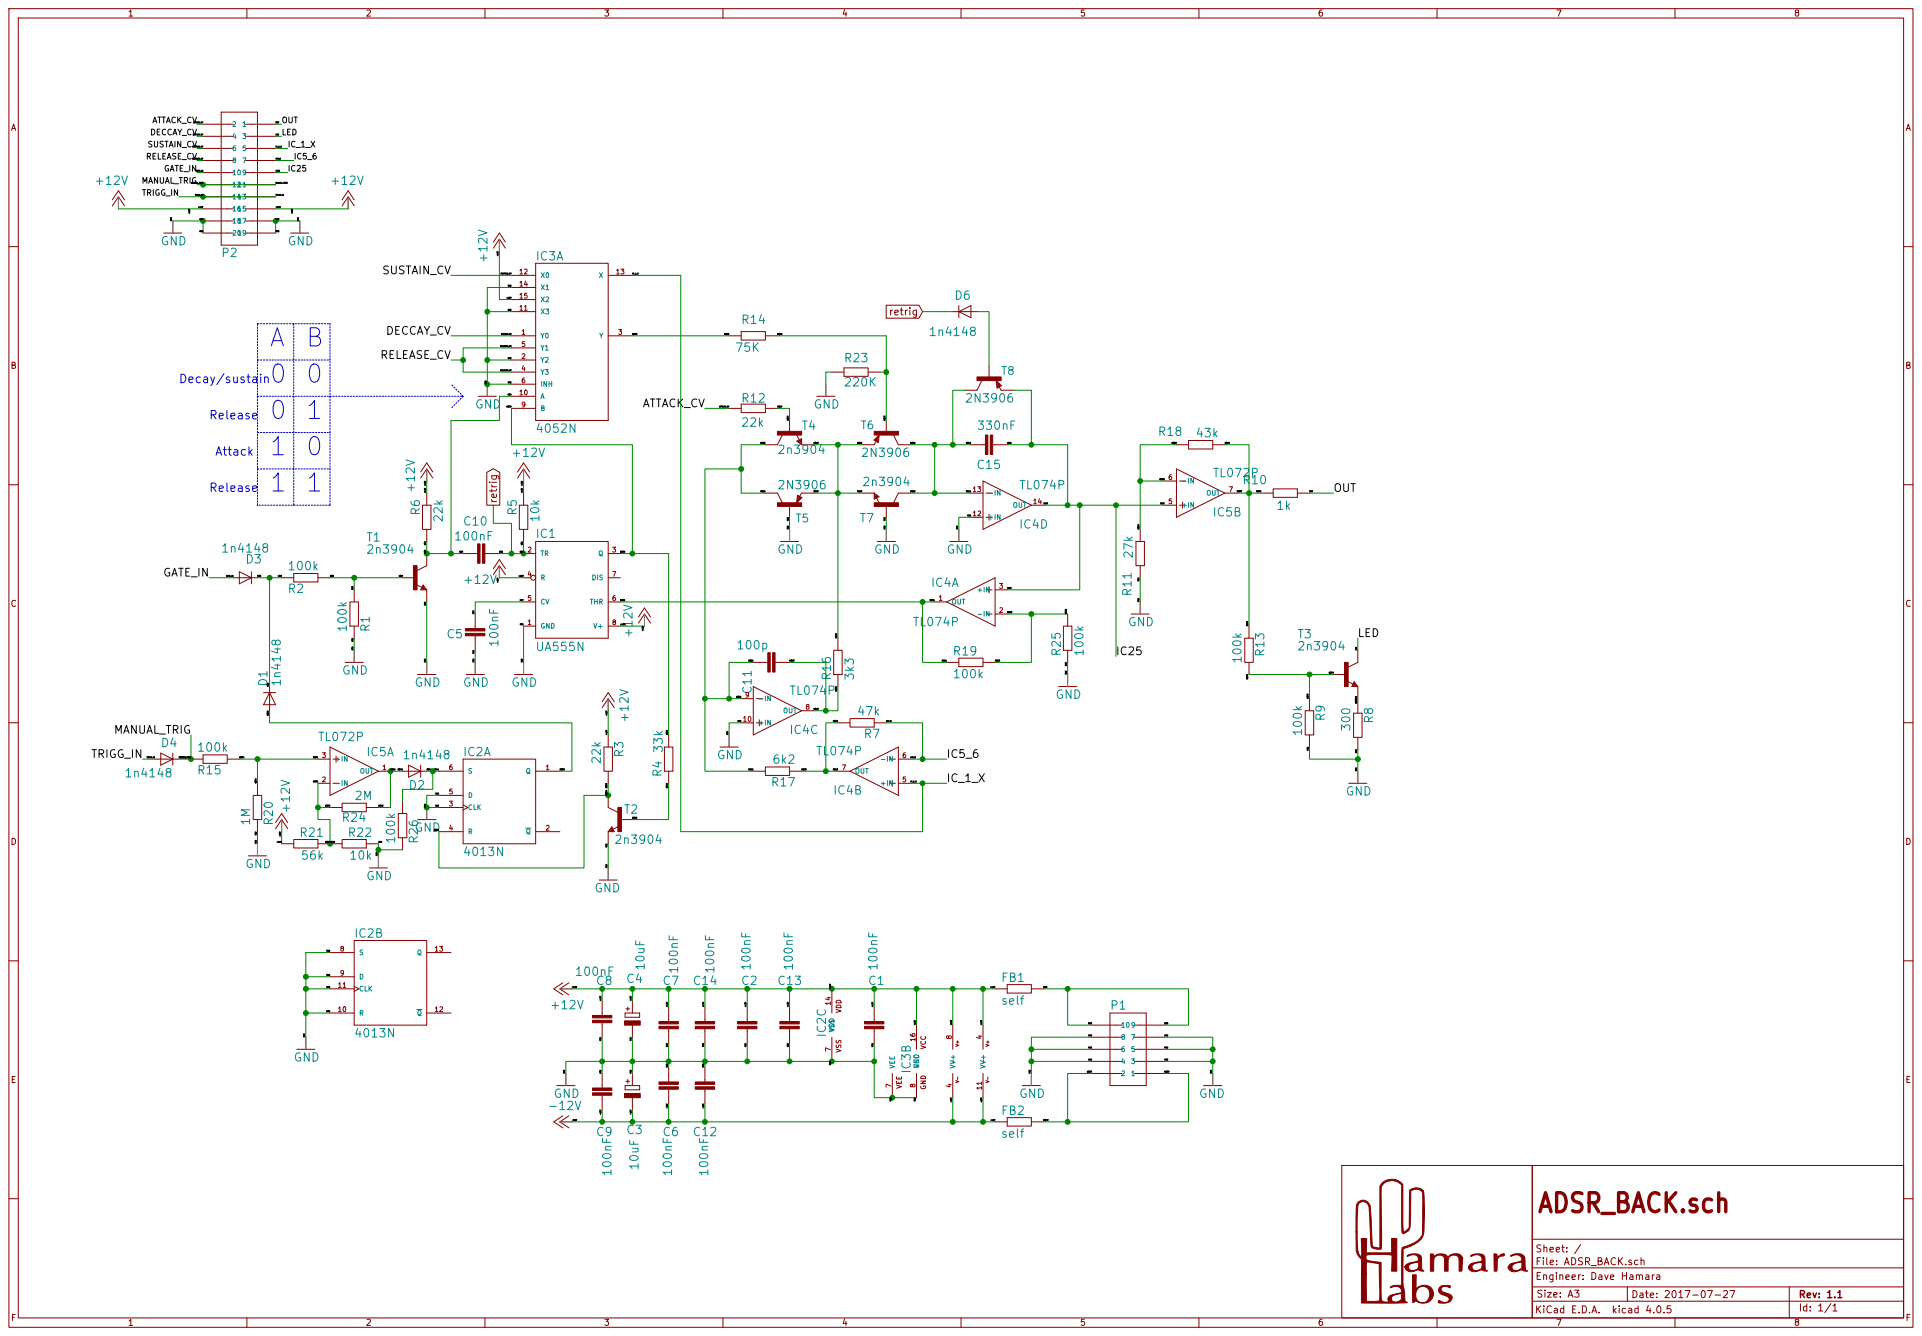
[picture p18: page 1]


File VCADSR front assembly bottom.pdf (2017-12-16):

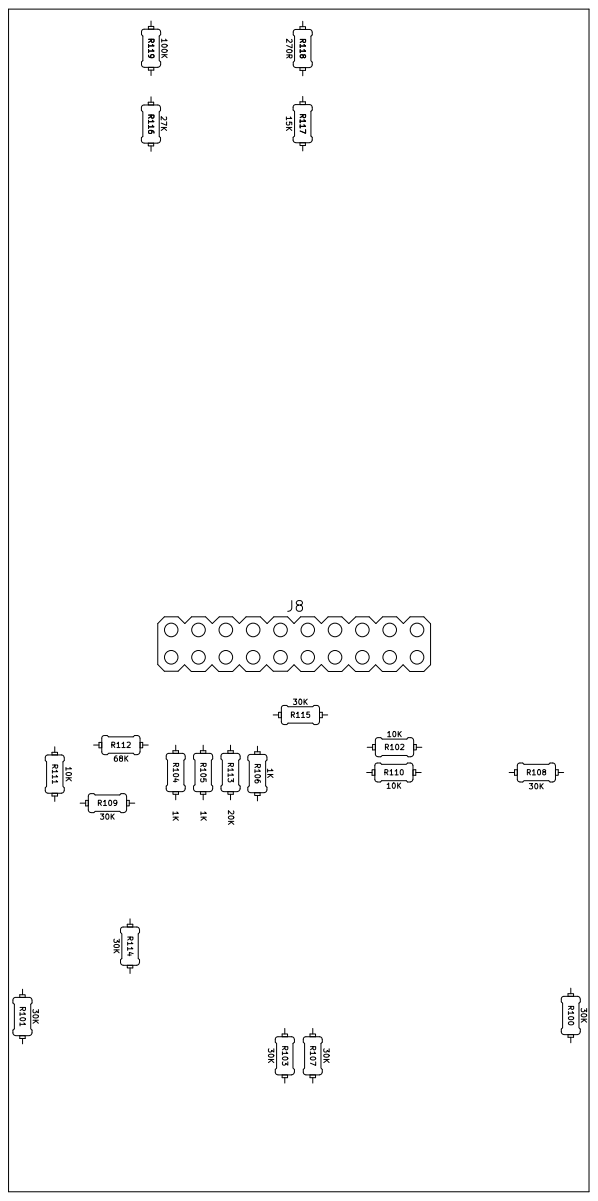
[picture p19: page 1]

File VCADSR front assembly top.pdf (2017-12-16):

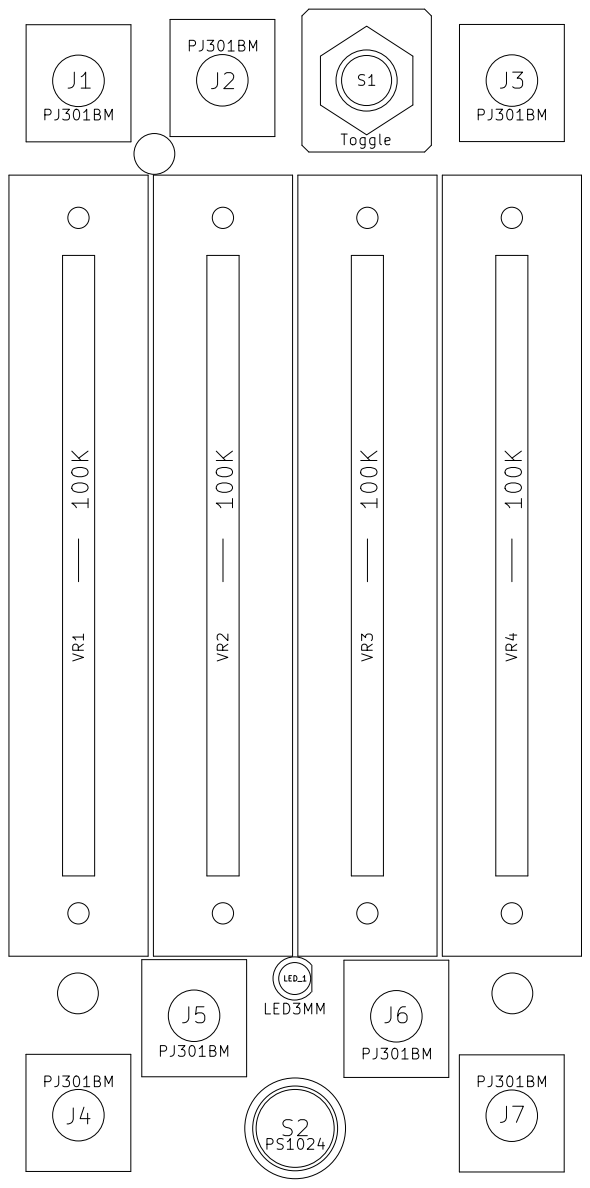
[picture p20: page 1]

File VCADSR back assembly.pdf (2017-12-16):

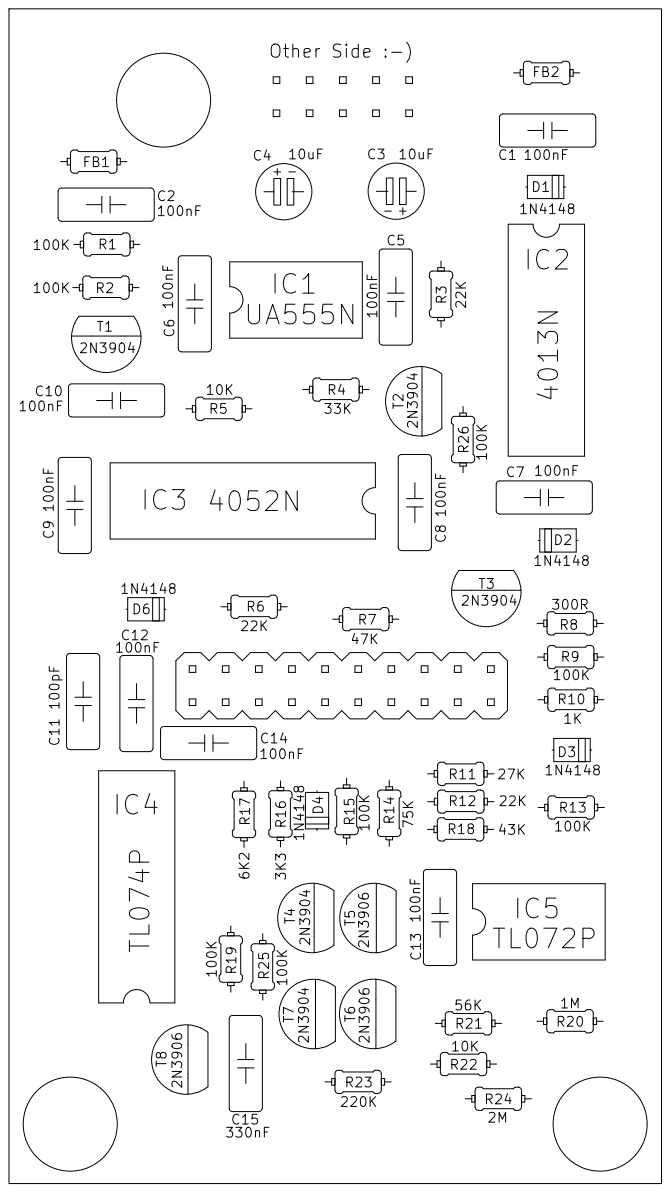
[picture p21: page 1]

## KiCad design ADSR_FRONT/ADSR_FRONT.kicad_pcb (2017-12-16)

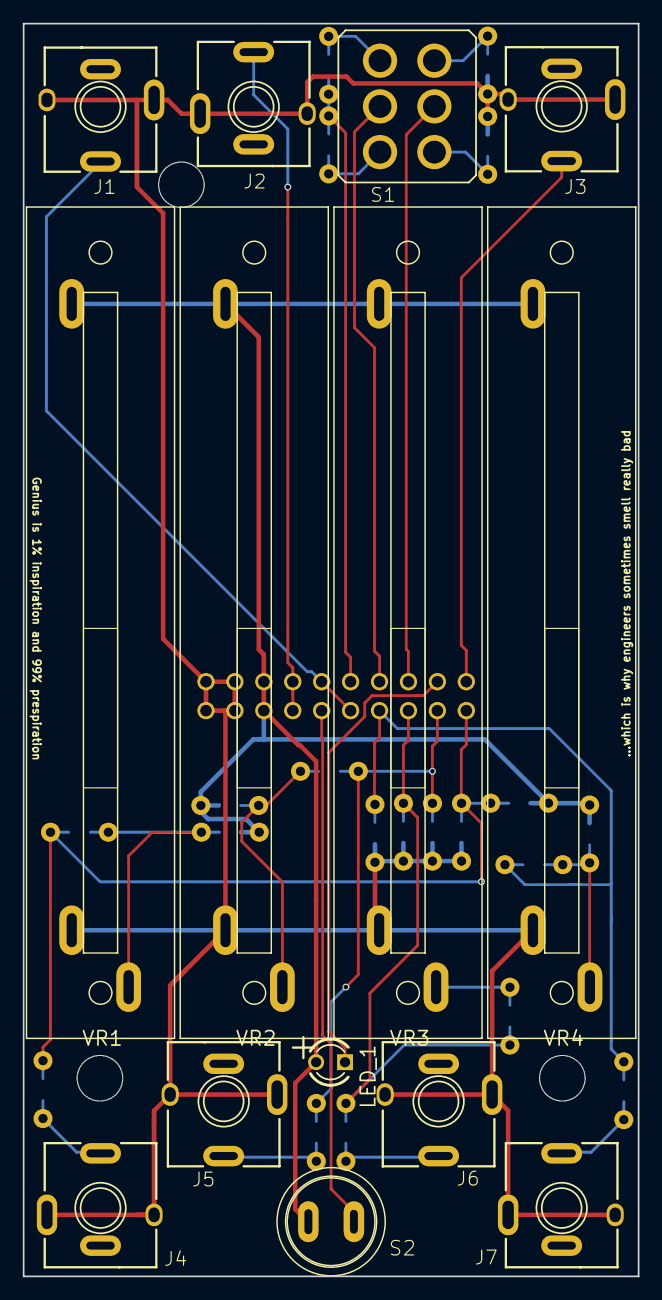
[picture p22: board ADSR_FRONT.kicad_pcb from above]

Board: 2 copper layers, 54.0 x 110.0 mm, 38 parts (0 on the bottom side), 26 nets.

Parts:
@HOLE0, @HOLE1, @HOLE2: Keystone_8848_spacer
J1, J2, J3, J4, J5, J6, J7: PJ301BM; PJ301BM-JACK-slots
J8: MA10-2
LED_1: LED3MM; Befaco_LED3MM
R100, R101, R103, R107, R108, R109, R114, R115: 30K; Befaco-0204_5_SMD
R102, R110, R111: 10K; Befaco-0204_5_SMD
R104, R105, R106: 1K; Befaco-0204_5_SMD
R112: 68K; Befaco-0204_5_SMD
R113: 20K; Befaco-0204_5_SMD
R116: 27K; Befaco-0204_5_SMD
R117: 15K; Befaco-0204_5_SMD
R118: 270R; Befaco-0204_5_SMD
R119: 100K; Befaco-0204_5_SMD
S1: Toggle; Befaco_DPDT_toggle
S2: PS1024; Button_PS1024
VR1, VR2, VR3, VR4: 100K; Befaco_VCADSR_SLIDER

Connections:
+12V: J8.15, J8.16, LED_1.A, R102.2, R110.2, R111.2, R112.1, S2.P$1, VR1.P$3, VR2.P$3, VR3.P$3, VR4.P$3
/N$2: R114.1, VR3.P$2
/N$3: J6.3, R103.1
/N$11: R119.2, S1.4
/N$14: R118.2, S1.1
/N$18: R117.2, S1.3
/N$24: J4.3, R100.1
/N$27: R116.2, S1.6
/N$46: R108.1, R110.1, VR1.P$2
/N$48: R109.1, R111.1, VR4.P$2
/N$49: R102.1, R115.1, VR2.P$2
/N$50: J7.3, R101.1
/N$51: J5.3, R107.1
GND: J1.1, J1.4, J2.1, J2.4, J3.1, J3.4, J4.1, J4.4, J5.1, J5.4, J6.1, J6.4, J7.1, J7.4, J8.17, J8.18, J8.19, J8.20, R104.2, R105.2, R106.2, R113.2, R116.1, R119.1, VR1.P$1, VR2.P$1, VR3.P$1, VR4.P$1
TO_ATTACK_CV: J8.1, R100.2, R104.1, R108.2, R112.2
TO_DECCAY_CV: J8.3, R105.1, R107.2, R115.2
TO_GATE_IN: J1.3, J8.9, J8.12
TO_IC2_5: J8.10, R117.1, R118.1
TO_IC5_6: J8.8, S1.2
TO_IC_1_X: J8.6, S1.5
TO_LED: J8.4, LED_1.K
TO_MANUAL_TRIG: J8.11, S2.P$2
TO_OUT: J3.3, J8.2
TO_RELEASE_CV: J8.7, R101.2, R106.1, R109.2
TO_SUSTAIN_CV: J8.5, R103.2, R113.1, R114.2
TO_TRIGG_IN: J2.3, J8.13, J8.14

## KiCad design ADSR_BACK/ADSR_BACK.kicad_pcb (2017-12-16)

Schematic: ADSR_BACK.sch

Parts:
C1, C2, C5, C6, C7, C8, C9, C10, C12, C13, C14: 100nF; RCL_C050-025X075
C3, C4: 10uF; RCL_E2-4
C11: 100p; RCL_C050-025X075
C15: 330nF; RCL_C050-025X075
D1, D2, D3, D4, D6: 1n4148; DIODE_D-5
FB1, FB2: self; RCL_0204_5
IC1: UA555N; LINEAR_DIL08
IC2: 4013N; 40XX_DIL14
IC3: 4052N; 40XX_DIL16
IC4: TL074P; LINEAR_DIL14
IC5: TL072P; LINEAR_DIL08
P1: power; CON-ML_ML10
P2: CON-LSTB_MA10-2
R1, R2, R9, R13, R15, R19, R25, R26: 100k; RCL_0204_5
R3, R6, R12: 22k; RCL_0204_5
R4: 33k; RCL_0204_5
R5, R22: 10k; RCL_0204_5
R7: 47k; RCL_0204_5
R8: 300; RCL_0204_5
R10: 1k; RCL_0204_5
R11: 27k; RCL_0204_5
R14: 75K; RCL_0204_5
R16: 3k3; RCL_0204_5
R17: 6k2; RCL_0204_5
R18: 43k; RCL_0204_5
R20: 1M; RCL_0204_5
R21: 56k; RCL_0204_5
R23: 220K; RCL_0204_5
R24: 2M; RCL_0204_5
T1, T2, T3, T4, T7: 2n3904; TRANSISTOR-NEU-TO92_TO92-EBC
T5, T6, T8: 2N3906; TRANSISTOR-NEU-TO92_TO92-EBC

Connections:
+12V: C1.2, C2.2, C4.+, C7.2, C8.2, C13.2, C14.2, FB1.1, IC1.4 (R), IC1.8 (V+), IC2.14 (VDD), IC3.15 (X2), IC3.16 (VCC), IC4.4 (V+), IC5.8 (V+), P2.15, P2.16, R3.1, R5.1, R6.1, R21.2
-12V: C3.-, C6.1, C9.1, C12.1, FB2.1, IC4.11 (V-), IC5.4 (V-)
/ATTACK_CV: P2.2, R12.1
/DECCAY_CV: IC3.1 (Y0), P2.4
/GATE_IN: D3.A, P2.10
/IC5_6: IC4.6 (-IN), P2.7, R7.1
/IC25: C15.2, IC4.3 (+IN), IC4.14 (OUT), IC5.5 (+IN), P2.9, T8.E
/IC_1_X: IC3.13 (X), IC4.5 (+IN), P2.5
/LED: P2.3, T3.C
/MANUAL_TRIG: D4.C, P2.11, P2.12, R15.1
/N$4: C10.2, IC3.10 (A), R6.2, T1.C
/N$5: D1.C, D3.C, R2.1
/N$6: R1.2, R2.2, T1.B
/N$7: C5.1, IC1.5 (CV)
/N$8: FB1.2, P1.9, P1.10
/N$10: R16.2, T4.E, T5.E, T6.E, T7.E
/N$12: C15.1, IC4.13 (-IN), T6.C, T7.C, T8.C
/N$13: IC4.7 (OUT), R7.2, R17.1
/N$15: R4.1, T2.B
/N$16: R14.2, R23.2, T6.B
/N$17: R12.2, T4.B
/N$19: IC3.3 (Y), R14.1
/N$21: IC1.6 (THR), IC4.1 (OUT), R19.1
/N$22: C11.1, IC4.9 (-IN), R17.2, T4.C, T5.C
/N$23: C11.2, IC4.8 (OUT), R16.1
/N$28: IC4.2 (-IN), R19.2, R25.2
/N$29: IC5.6 (-IN), R11.1, R18.2
/N$30: IC5.7 (OUT), R10.2, R13.1, R18.1
/N$33: FB2.2, P1.1, P1.2
/N$34: IC5.3 (+IN), R15.2, R20.2
/N$35: D1.A, IC2.1 (Q)
/N$36: IC1.3 (Q), IC3.9 (B), R4.2
/N$38: IC2.4 (R), R3.2, T2.C
/N$39: IC5.2 (-IN), R21.1, R22.2, R24.2
/N$41: D2.C, IC2.6 (S), R26.2
/N$42: D2.A, IC5.1 (OUT), R24.1
/N$78: R8.1, T3.E
/N$79: R9.1, R13.2, T3.B
/OUT: P2.1, R10.1
/RELEASE_CV: IC3.4 (Y3), IC3.5 (Y1), P2.8
/SUSTAIN_CV: IC3.12 (X0), P2.6
/TRIGG_IN: D4.A, P2.13, P2.14
GND: C1.1, C2.1, C3.+, C4.-, C5.2, C6.2, C7.1, C8.1, C9.2, C12.2, C13.1, C14.1, IC1.1 (GND), IC2.3 (CLK), IC2.5 (D), IC2.7 (VSS), IC2.8 (S), IC2.9 (D), IC2.10 (R), IC2.11 (CLK), IC3.2 (Y2), IC3.6 (INH), IC3.7 (VEE), IC3.8 (GND), IC3.11 (X3), IC3.14 (X1), IC4.10 (+IN), IC4.12 (+IN), P1.3, P1.4, P1.5, P1.6, P1.7, P1.8, P2.17, P2.18, P2.19, P2.20, R1.1, R8.2, R9.2, R11.2, R20.1, R22.1, R23.1, R25.1, R26.1, T1.E, T2.E, T5.B, T7.B
unnamed: D6.A, T8.B
retrig: C10.1, D6.C, IC1.2 (TR), R5.2

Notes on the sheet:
Decay/sustain
Release
Attack

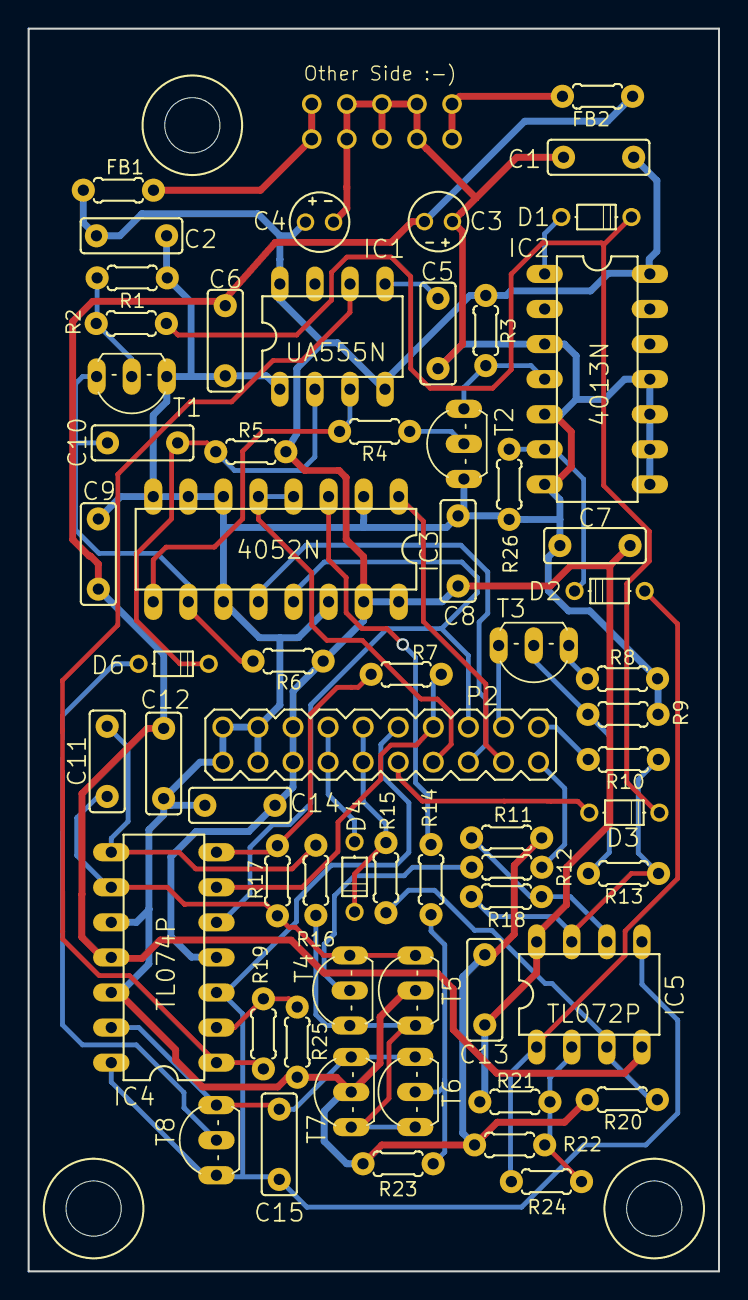
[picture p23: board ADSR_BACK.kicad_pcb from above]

Board: 2 copper layers, 50.0 x 90.0 mm, 66 parts (0 on the bottom side), 45 nets.

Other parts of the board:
@HOLE0, @HOLE1, @HOLE2: Keystone_8848_spacer

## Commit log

2017-12-16 First commit of ADSR_BACK
    [ADSR_BACK.kicad_pcb, ADSR_BACK.sch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]
2017-12-16 Uploading full local repository
    [ADSR_FRONT.kicad_pcb, ADSR_FRONT.sch, panel_v2.kicad_pcb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]
2017-12-16 Add link to BOM, links to original sources, warranty disclaimer
2017-12-16 Uploading a few stragglers
    [panel_v2-Edge.Cuts.gm1, panel_v2-F.Cu.gtl, panel_v2-F.Mask.gts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]
2017-12-16 Add link to BOM, links to original design sources, and warranty disclaimer
2017-12-16 Add link to BOM, links to original design sources, warranty disclaimer.

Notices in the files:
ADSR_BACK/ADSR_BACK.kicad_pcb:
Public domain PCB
